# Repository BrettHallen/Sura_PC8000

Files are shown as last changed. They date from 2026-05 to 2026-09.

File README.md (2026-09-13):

# СУРА ПК8000<br>SURA PC8000
Projects for the Soviet "inspired by MSX" computer called the СУРА ПК8000.<br>

Also known as the ВЕСТА (Vesta) and ХОББИ (Hobby).

## YouTube Videos
- [Part 1: First look](https://youtu.be/wWDCWSeaxUg)
- [Part 2: New power supply test](https://youtu.be/me7krCPeANg)

## Useful Links
Mostly in Russian - I use Chrome which has a handy "Translate to English" right-click option.<br>

- [Wikipedia](https://ru.wikipedia.org/wiki/ПК8000)
- [PK8000 site](https://pk8000.narod.ru/)

## [Video Converter](/HDMI_Video_Adaptor_EN)
Work in progress - a video converter designed for Soviet computers.<br>
My only contribution is translating the Python script from Russian to English.<br>

## [PSU Replacement](/Sura_PSU)
Work in progress - my Sura's original 220VAC power supply is very unhappy.  This is my attempt at a simpler, universal (12VDC input) replacement.<br>

I have tested the original Rev. A design ... it works ... but I need to make some tweaks so there will be a Rev. B coming soon.<br>

The original PSU outputs the following via X11 interface:
|X11 port|Voltage|
|---|---|
| X11-5  | +5V |
| X11-6  | +5V |
| X11-8  | -12V  |
| X11-10 | 0V |
| X11-12 | +12V  |
| X11-24 | +12V  |
| X11-25 | +5V |
| X11-26 | +5V |
| X11-27 | 0V |

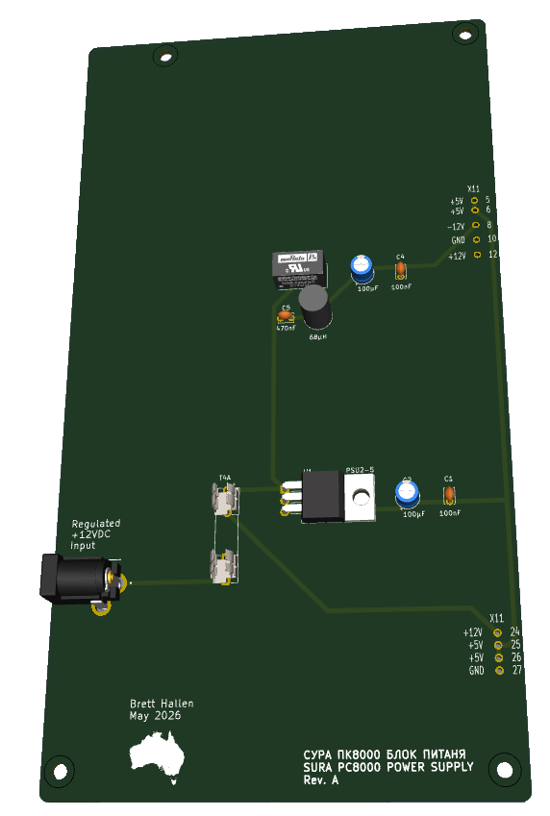
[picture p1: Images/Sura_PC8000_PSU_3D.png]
Replacement PSU 3D


## [Documentation](/Documentation)
Original documentation in Russian, plus any details I've created of my own.<br>
Documentation was sourced from the [PK8000 site](https://pk8000.narod.ru/).

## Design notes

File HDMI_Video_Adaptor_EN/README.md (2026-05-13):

# Video Converter
The hardware design can be found here:<br>
- https://murmulator.ru/rgbtovgahdmi
- https://github.com/AlexEkb4ever/ZX_RGBI2VGA-HDMI

There is a [long discussion thread](https://zx-pk.ru/threads/8375-pk8000-podklyuchaem-k-televizoru(monitoru)/page19.html) about customising, I think, for the PC8000.<br>

That is where I sourced the files here and started the Russian to English translation.<br>

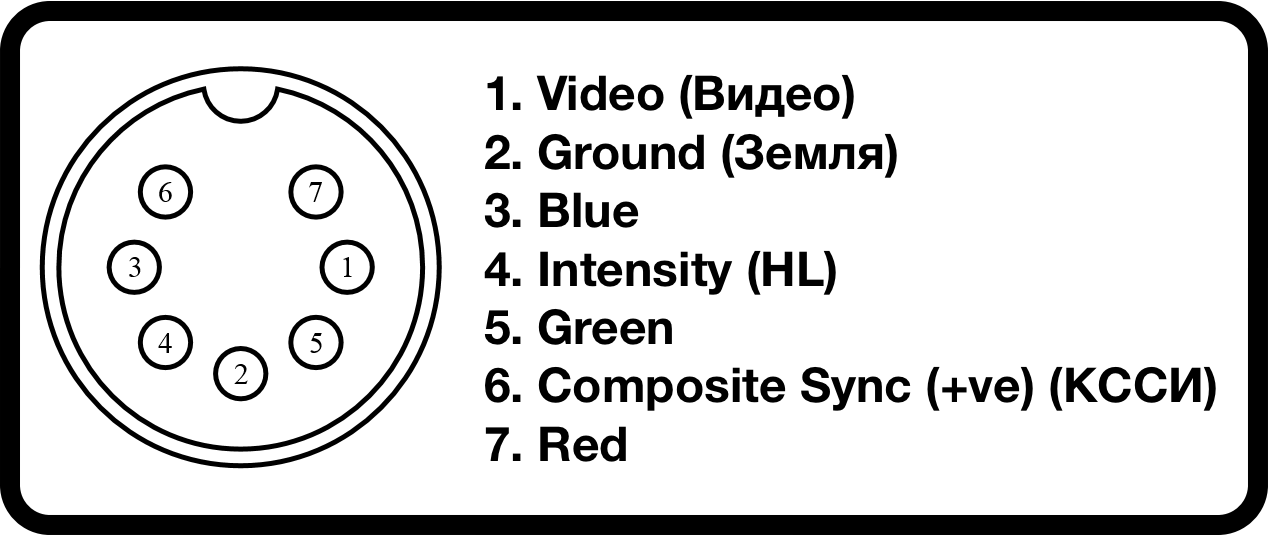
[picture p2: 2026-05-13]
Documentation/Sura_PC8000_Video Pinout.png

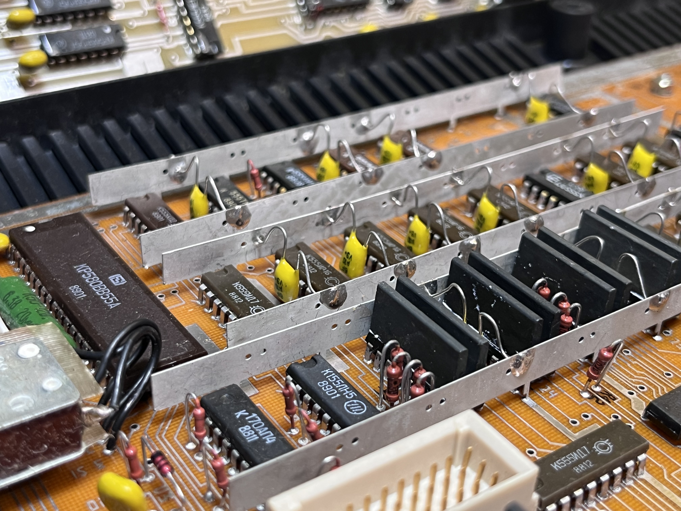
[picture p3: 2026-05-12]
Images/Sura_PC8000_Motherboard1.jpeg

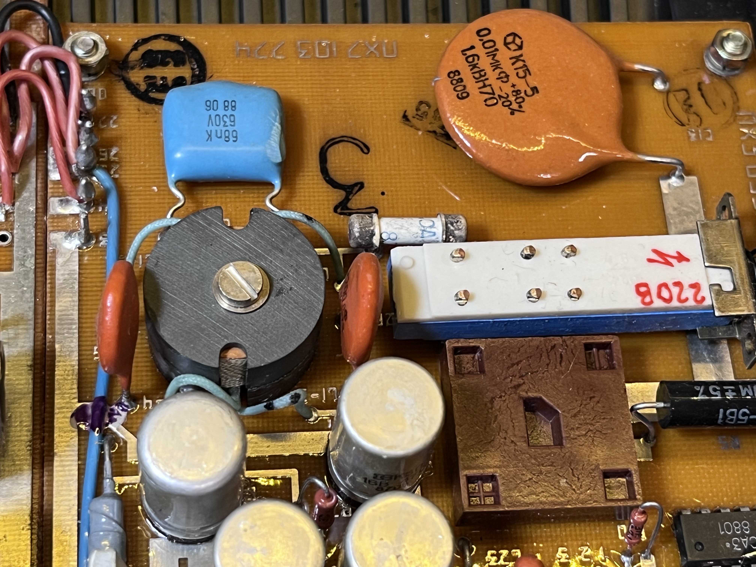
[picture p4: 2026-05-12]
Images/Sura_PC8000_PSU3.jpeg

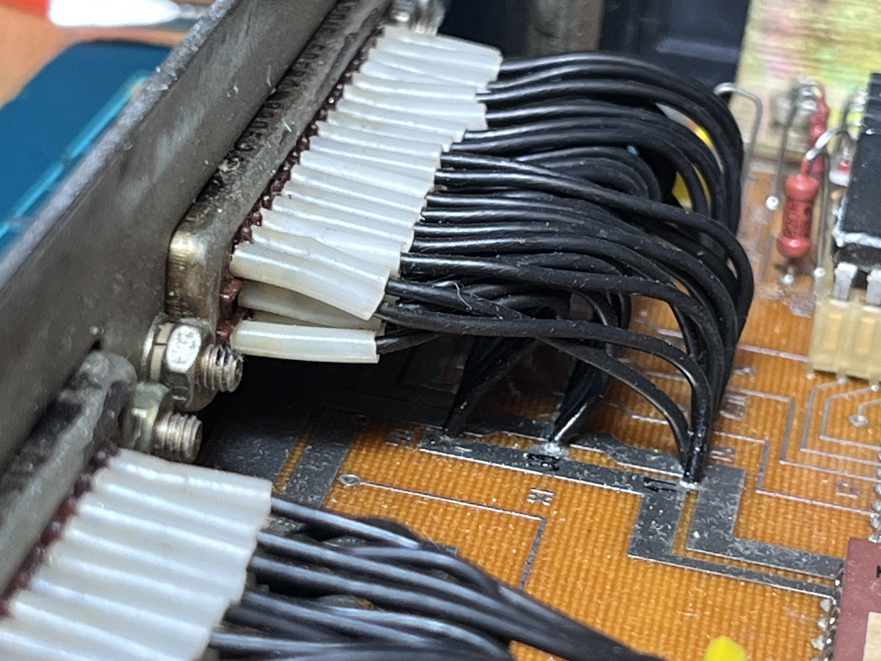
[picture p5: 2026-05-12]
Images/Sura_PC8000_DD50.jpeg

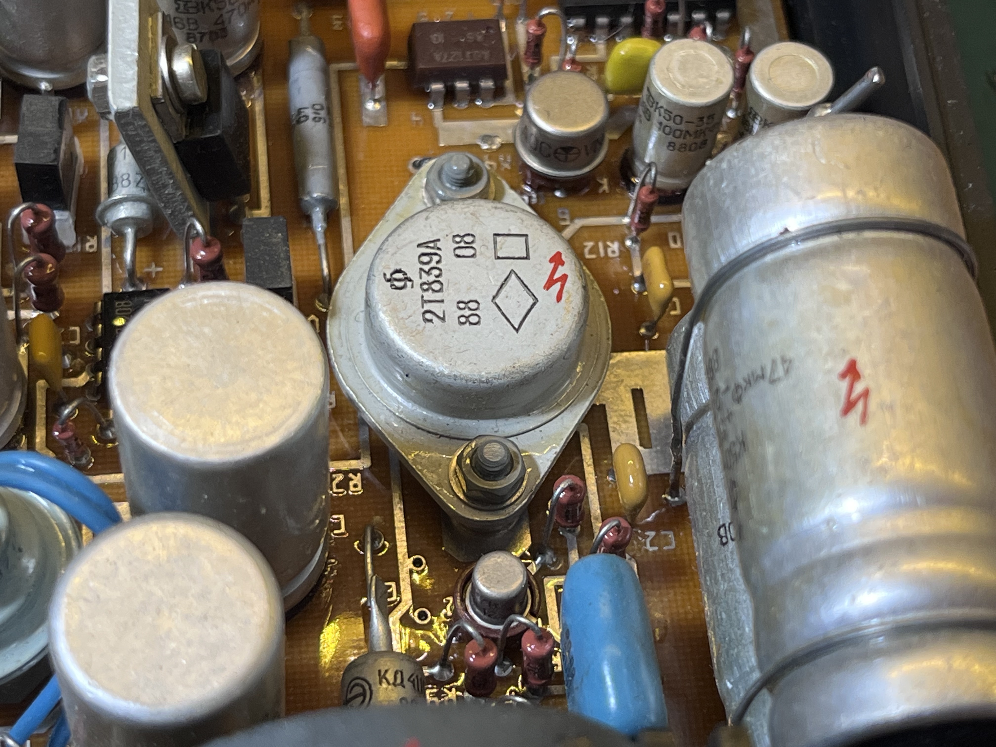
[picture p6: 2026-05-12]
Images/Sura_PC8000_PSU2.jpeg

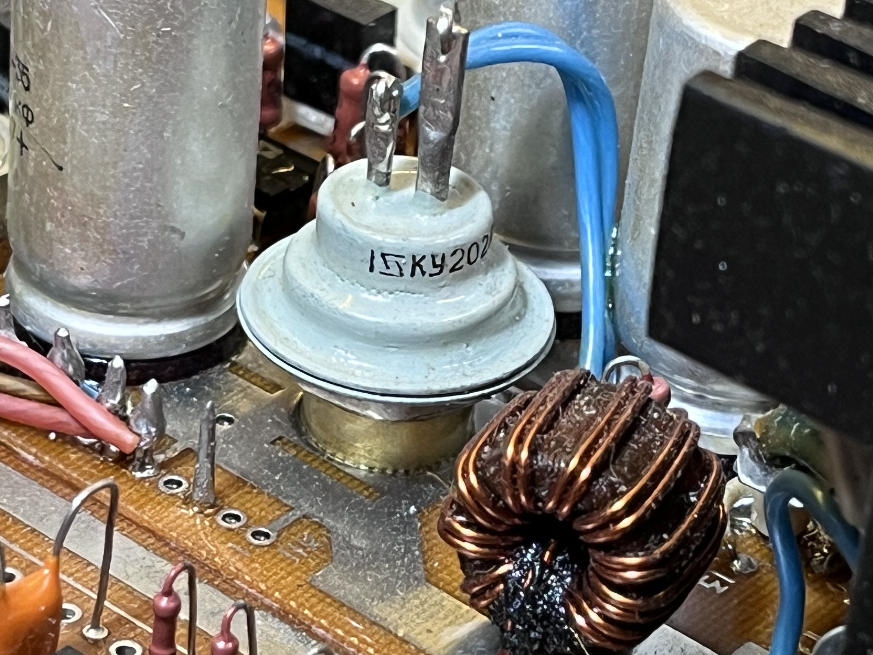
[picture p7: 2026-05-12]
Images/Sura_PC8000_PSU1.jpeg

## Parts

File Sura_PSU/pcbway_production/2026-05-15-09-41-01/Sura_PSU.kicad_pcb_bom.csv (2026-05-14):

Designator | Quantity | Value | Footprint | Package | MPN | DNP | Mount_Type | Description | Manufacturer_Name | Height
C1 | 1 | 22µF 16V | CP_Radial_D5.0mm_P2.50mm |  |  |  | tht | Polarized capacitor
C2 | 1 | 10µF 25V | CP_Radial_D5.0mm_P2.50mm |  |  |  | tht | Polarized capacitor
C3 | 1 | 100µF | CP_Radial_D5.0mm_P2.50mm |  |  |  | tht | Polarized capacitor
C4 | 1 | 100nF | C_Disc_D3.4mm_W2.1mm_P2.50mm |  |  |  | tht | Unpolarized capacitor
C5 | 1 | 470nF | C_Disc_D3.4mm_W2.1mm_P2.50mm |  |  |  | tht | Unpolarized capacitor
F1 | 1 | T4A | Fuseholder_Clip-5x20mm_Littelfuse_111_Inline_P20.00x5.00mm_D1.05mm_Horizontal |  |  |  | tht | Fuse
J1 | 1 | X11 | PinHeader_1x05_P2.54mm_Vertical |  |  |  | tht | Generic connector, single row, 01x05, script generated (kicad-library-utils/schlib/autogen/connector/)
J2 | 1 | 12V In | 694106301002 |  |  |  | tht | DC Barrel Jack with a mounting pin
J3 | 1 | X11 | PinHeader_1x04_P2.54mm_Vertical |  |  |  | tht | Generic connector, single row, 01x04, script generated (kicad-library-utils/schlib/autogen/connector/)
L1 | 1 | 68µH | 22R683C |  |  |  | tht | Inductor
U1 | 1 | DFR0831 | DFR0831 |  |  |  | tht | DC-DC Buck Converter 7-24V to 5V 4A | DFRobot
U2 | 1 | NKE1212SC | NKE1212SC |  | NKE1212SC |  | tht | Murata Power Solutions NKE 1W Isolated DC-DC Converter Through Hole, Voltage in 10.8 13.2 V dc, Voltage out | Murata Electronics | 7.71

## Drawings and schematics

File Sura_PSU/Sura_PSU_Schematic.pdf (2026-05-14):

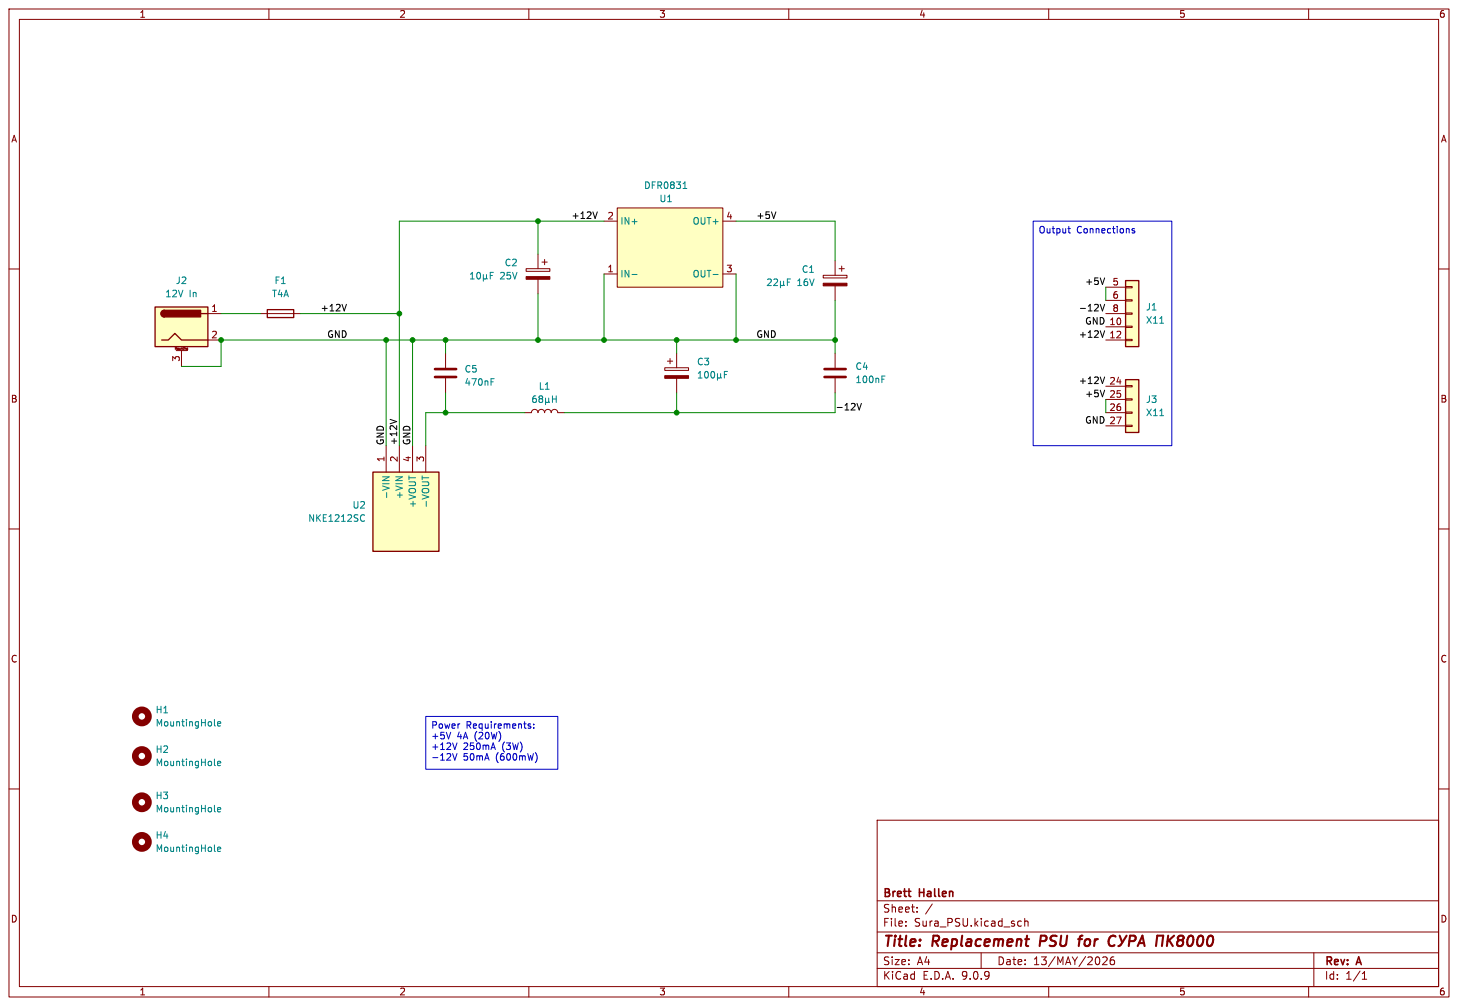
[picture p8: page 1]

12V In H3 MountingHole H4 MountingHole H1 MountingHole H2 MountingHole

Id: 1/1 Title: Replacement PSU for þÿ!# þÿ8000

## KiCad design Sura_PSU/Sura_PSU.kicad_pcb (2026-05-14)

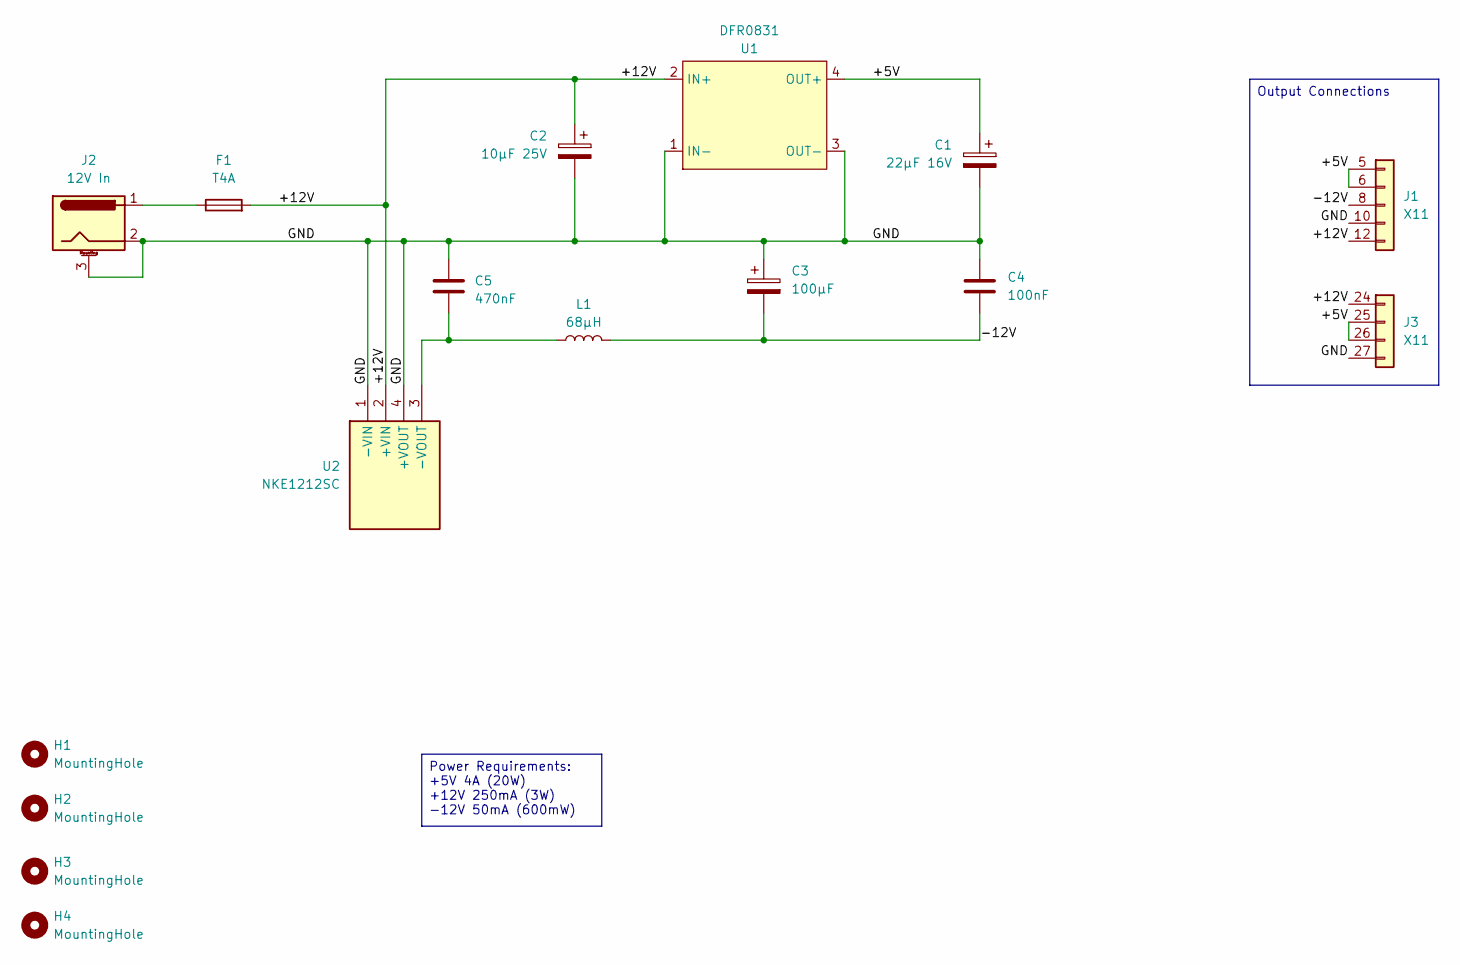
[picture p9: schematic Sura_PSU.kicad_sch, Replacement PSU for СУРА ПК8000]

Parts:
C1: 22µF 16V; CP_Radial_D5.0mm_P2.50mm
C2: 10µF 25V; CP_Radial_D5.0mm_P2.50mm
C3: 100µF; CP_Radial_D5.0mm_P2.50mm
C4: 100nF; C_Disc_D3.4mm_W2.1mm_P2.50mm
C5: 470nF; C_Disc_D3.4mm_W2.1mm_P2.50mm
F1: T4A; Fuseholder_Clip-5x20mm_Littelfuse_111_Inline_P20.00x5.00mm_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
H1, H2, H3, H4: MountingHole; MountingHole_3.2mm_M3
J1: X11; PinHeader_1x05_P2.54mm_Vertical
J2: 12V In; 694106301002
J3: X11; PinHeader_1x04_P2.54mm_Vertical
L1: 68µH; 22R683C
U1: DFR0831
U2: NKE1212SC; Manufacturer_Part_Number NKE1212SC

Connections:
/+5V: C1.1, J1.5 (Pin_1), J1.6 (Pin_2), J3.25 (Pin_2), J3.26 (Pin_3), U1.4 (OUT+)
/+12V: C2.1, F1.2, J1.12 (Pin_5), J3.24 (Pin_1), U1.2 (IN+), U2.2 (+VIN)
/-12V: C3.2, C4.2, J1.8 (Pin_3), L1.2
/GND: C1.2, C2.2, C3.1, C4.1, C5.2, J1.10 (Pin_4), J2.2, J2.3 (MountPin), J3.27 (Pin_4), U1.1 (IN-), U1.3 (OUT-), U2.1 (-VIN), U2.4 (+VOUT)
unnamed: F1.1, J2.1
unnamed: C5.1, L1.1, U2.3 (-VOUT)

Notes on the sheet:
Power Requirements: +5V 4A (20W) +12V 250mA (3W) -12V 50mA (600mW)
Output Connections

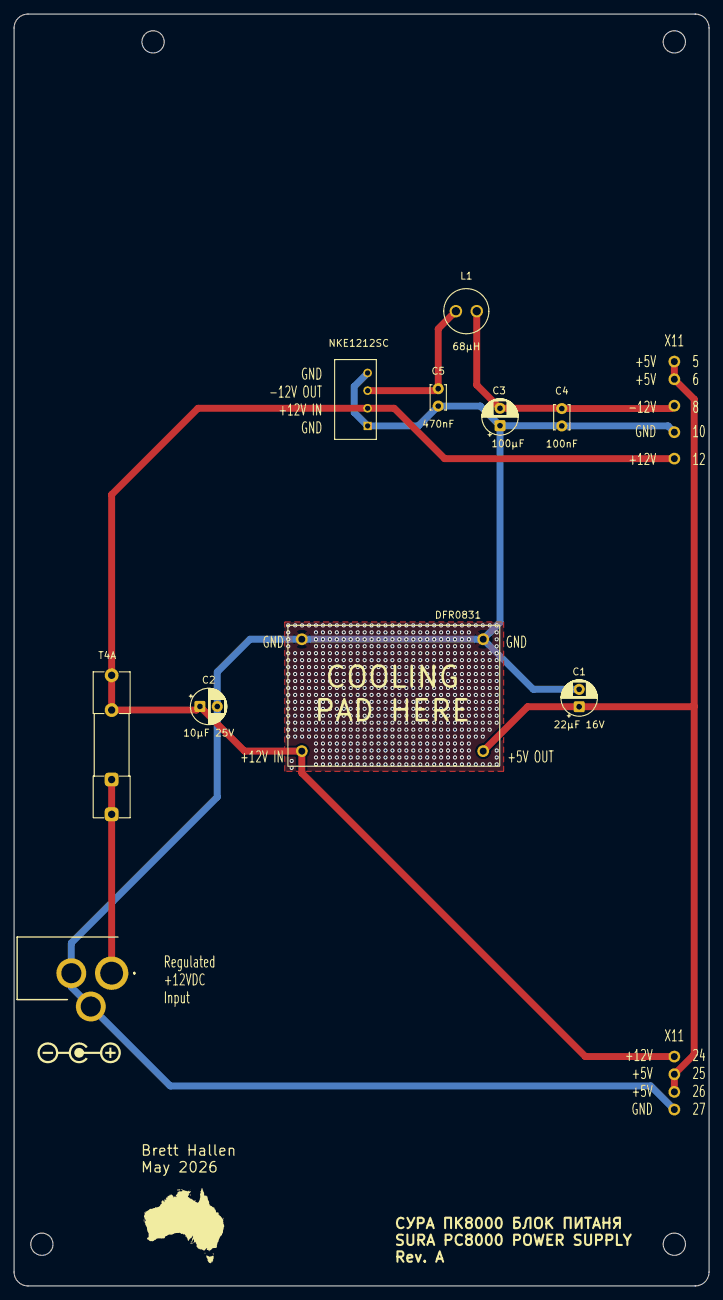
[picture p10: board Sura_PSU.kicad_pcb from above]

Board: 2 copper layers, 100.0 x 183.0 mm, 16 parts (0 on the bottom side), 6 nets.

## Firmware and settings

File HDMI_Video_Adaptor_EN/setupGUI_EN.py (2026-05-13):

# -*- coding: utf-8 -*-

import PySimpleGUI as sg
#import serial.tools.list_ports
import time

import re
import sys
import glob
import serial


def write_ser(ser, key, value):
    return True


def serial_ports():
    """ Lists serial port names

        :raises EnvironmentError:
            On unsupported or unknown platforms
        :returns:
            A list of the serial ports available on the system
    """
    if sys.platform.startswith('win'):
        ports = ['COM%s' % (i + 1) for i in range(256)]
    elif sys.platform.startswith('linux') or sys.platform.startswith('cygwin'):
        # this excludes your current terminal "/dev/tty"
        ports = glob.glob('/dev/tty[A-Za-z]*')
    elif sys.platform.startswith('darwin'):
        ports = glob.glob('/dev/tty.*')
    else:
        raise EnvironmentError('Unsupported platform')

    result = []
    for port in ports:
        try:
            s = serial.Serial(port)
            s.close()
            result.append(port)
        except (OSError, serial.SerialException):
            pass
    return result


# Default theme
sg.change_look_and_feel('SystemDefaultForReal')  # GreenTan

# Get list of serial ports
dev_TTY = serial_ports()  # v2
if len(dev_TTY) == 0:
    dev_TTY = [""]
    sg.PopupNoButtons("No serial ports found", auto_close=True)
    sys.exit()


# Draw the button
namesMode = ('Self-synchronization', 'External frequency', 'From Z80 pin 6')


comboBoxMode = sg.Combo(namesMode, default_value=namesMode[0], size=(20, 1), key='modeName', readonly=True)
comboBoxPorts = sg.InputCombo(dev_TTY, default_value=dev_TTY[0], size=(40, 1), key='portName', readonly=True)

sliderX = sg.Frame(layout=[[
    sg.Slider((200, 0), orientation='h', enable_events=True, key='SLIDERX')
]], title="X Offset", title_location=sg.TITLE_LOCATION_TOP, key='settingsBlock')

sliderY = sg.Frame(layout=[[
    sg.Slider((0, 200), orientation='h', enable_events=True, key='SLIDERY')
]], title="Y Offset", title_location=sg.TITLE_LOCATION_TOP, key='settingsBlock')

sliderF = sg.Frame(layout=[[
    sg.Slider((4000, 11000), orientation='h', enable_events=True, key='-SLIDERF-', size=(250, 20))
]], title="Internal Capture Frequency (kHz)", title_location=sg.TITLE_LOCATION_TOP, key='setting_F_Block')

dividerF = sg.Frame(layout=[[
    sg.Slider((1, 5), orientation='h', enable_events=True, key='-SLIDER_f_div-')
]], title="Divider", title_location=sg.TITLE_LOCATION_TOP, key='dividerFblock')

slider_VS_LEN = sg.Frame(layout=[[
    sg.Slider((50, 500), orientation='h', enable_events=True, key='-SLIDER_VS_LEN-')
]], title="VS Length", title_location=sg.TITLE_LOCATION_TOP, key='settings_VS_LEN_Block')

invBlock = sg.Frame(layout=[[
    sg.CBox('F', size=(3, 1), key='is_inv_F'),
    sg.CBox('KSI', size=(3, 1), key='is_inv_VS'),
    sg.CBox('SSI', size=(3, 1), key='is_inv_HS'),
    sg.CBox('I', size=(3, 1), key='is_inv_I'),
    sg.CBox('R', size=(3, 1), key='is_inv_R'),
    sg.CBox('G', size=(3, 1), key='is_inv_G'),
    sg.CBox('B', size=(3, 1), key='is_inv_B'),
]], title="Invert Input Signals", title_location=sg.TITLE_LOCATION_TOP, key='setting_inv_Block')

sliderDelay0 = sg.Slider((0, 31), orientation='h', enable_events=True, key='-SLIDER_DELAY_0-')

sliderDelay1 = sg.Frame(layout=[[
    sg.Slider((0, 31), orientation='h', enable_events=True, key='-SLIDER_DELAY_1-')
]], title="Rising Edge", title_location=sg.TITLE_LOCATION_TOP, key='-SLIDER_DELAY_BLOCK1-')

sliderDelay2 = sg.Frame(layout=[[
    sg.Slider((0, 31), orientation='h', enable_events=True, key='-SLIDER_DELAY_2-')
]], title="Falling Edge", title_location=sg.TITLE_LOCATION_TOP, key='-SLIDER_DELAY_BLOCK2-')

syncSelect = sg.Frame(layout=[[sg.Radio('Separate', "SYNCMODE", default=True, key="isVS_HS"),
                               sg.Radio('Composite', "SYNCMODE", key="isVHS")],
                              [sg.Push(), slider_VS_LEN, sg.Push()]],
                      title="Synchronization", title_location=sg.TITLE_LOCATION_TOP)

btn1 = sg.Button('Apply', size=(10, 1), key="btn1Click")

block0 = [
    [sg.Frame(layout=[[sg.Radio('VGA', "VIDEOMODE", default=True, size=(5, 1), key="isVGAout", disabled=False),
                       sg.Radio('HDMI', "VIDEOMODE", key="isHDMIout", disabled=False)],
                      [sg.Radio('RGB', "VIDEOMODE", size=(5, 1), key="isRGBout", disabled=True),
                       sg.Radio('COMP', "VIDEOMODE", key="isCOMPout", disabled=True)],
                      [
                          sg.Push(),
                          sg.Frame(layout=[[sg.CBox('Widescreen', key='is_widescreen', disabled=True)]],
                                   title="Aspect Ratio", title_location=sg.TITLE_LOCATION_TOP, key="WIDE_MODE_BLOCK"),
                          sg.Push()
                      ],
                      [
                          sg.Frame(layout=[[sg.Radio('PAL (50Hz)', "SYS_COLOR_MODE", default=True, key="isPAL", disabled=False),
                                            sg.Radio('NTSC (60Hz)', "SYS_COLOR_MODE", key="isNTSC", disabled=False)]],
                                   title="Standard", title_location=sg.TITLE_LOCATION_TOP, key="C_MODE_BLOCK")
                      ]],
               title="Video Output", title_location=sg.TITLE_LOCATION_TOP),

     sg.Frame(layout=[[sg.Radio('1X', "BUFMODE", default=True, size=(5, 1), key="is1X_BUFMODE", disabled=False),
                       sg.Radio('3X', "BUFMODE", key="is3X_BUFMODE", disabled=False)]],
              title="Buffering", title_location=sg.TITLE_LOCATION_TOP)
    ],

    [sg.Frame(layout=[[comboBoxPorts]], title="Port Selection",
              title_location=sg.TITLE_LOCATION_TOP, key='portNameBlock')]
]

block1 = [[
    syncSelect,
    sg.Frame(layout=[[comboBoxMode], [dividerF]],
             title="Pixel Clock Source", title_location=sg.TITLE_LOCATION_TOP)
],

    [sliderF]
]

block2 = [[sg.Frame(layout=[

    [sg.Push(), sliderX, sliderY, sg.Push()],

    [sg.Push(), sg.Frame(layout=[[sliderDelay1, sliderDelay2],
                                 [sg.Push(), sliderDelay0, sg.Push()]],
                        title="Capture Delay", title_location=sg.TITLE_LOCATION_TOP, key='delay_cap_block'), sg.Push()],

    [sg.Push(), invBlock, sg.Push()],

], title="", title_location=sg.TITLE_LOCATION_TOP, key='settingsBlock')]]

blockBTN = [[btn1]]

layout = [
    [sg.Push(), sg.Column(layout=block0, element_justification='c'), sg.Push()],

    [sg.Push(), sg.Column(layout=block1, element_justification='c'), sg.Push()],

    [sg.Push(), sg.Column(layout=block2, element_justification='c'), sg.Push()],

    [sg.Push(), sg.Column(layout=blockBTN, element_justification='c'), sg.Push()],
]

# Draw the window
window = sg.Window('RGB to VGA & HDMI Settings', layout, font=('', 12), margins=(10, 0),
                   size=(600, 650), default_element_size=(40, 1), scaling=True, grab_anywhere=False)

ser = None
oldSerName = None
itst = 0
x_sh = '0'
y_sh = '0'
l_mode = 'read'

while True:
    event, values = window.read(timeout=100)
    if event is None:
        break

    # Check serial port connection
    xnew = int(values['SLIDERX'])
    ynew = int(values['SLIDERY'])

    if event == '__TIMEOUT__':
        # Change of serial port
        if comboBoxPorts.get() != oldSerName:
            if l_mode != 'write':
                l_mode = 'read'
            ser_name = comboBoxPorts.get()
            if ser is None:
                while ser is None:
                    try:
                        ser = serial.Serial(ser_name, 115200, timeout=0.001)
                        oldSerName = ser_name
                    except:
                        ser = None
                        print("create serial " + ser_name + " error")
                        time.sleep(1)
            else:
                ser.close()
                ser = serial.Serial(ser_name, 115200, timeout=0.001)
                oldSerName = ser_name

    # Saving all settings
    if event == 'btn1Click':
        sg.PopupNoButtons("Rebooting board, please wait...", auto_close=True)
        l_mode = 'write'

    # Mode selection
    modeName = window['modeName'].get()

    if modeName == namesMode[0]:  # Self-synchronization
        window['dividerFblock'].hide_row()
        window['setting_F_Block'].unhide_row()
        window['-SLIDER_DELAY_0-'].unhide_row()
        window['-SLIDER_DELAY_BLOCK1-'].hide_row()
        window['-SLIDER_DELAY_BLOCK2-'].hide_row()

    if modeName == namesMode[1]:  # External frequency
        window['dividerFblock'].unhide_row()
        window['setting_F_Block'].hide_row()
        window['-SLIDER_DELAY_0-'].unhide_row()
        window['-SLIDER_DELAY_BLOCK1-'].hide_row()
        window['-SLIDER_DELAY_BLOCK2-'].hide_row()

    if modeName == namesMode[2]:  # From Z80 pin 6
        window['dividerFblock'].hide_row()
        window['setting_F_Block'].hide_row()
        window['-SLIDER_DELAY_0-'].hide_row()
        window['-SLIDER_DELAY_BLOCK1-'].unhide_row()
        window['-SLIDER_DELAY_BLOCK2-'].unhide_row()

    if window['isHDMIout'].get():
        window['C_MODE_BLOCK'].hide_row()
        window['WIDE_MODE_BLOCK'].unhide_row()

    if window['isVGAout'].get():
        window['C_MODE_BLOCK'].hide_row()
        window['WIDE_MODE_BLOCK'].unhide_row()

    if window['isRGBout'].get():
        window['C_MODE_BLOCK'].unhide_row()
        window['WIDE_MODE_BLOCK'].hide_row()

    if window['isCOMPout'].get():
        window['C_MODE_BLOCK'].unhide_row()
        window['WIDE_MODE_BLOCK'].hide_row()

    if window['isVHS'].get():
        window['settings_VS_LEN_Block'].unhide_row()
    if window['isVS_HS'].get():
        window['settings_VS_LEN_Block'].hide_row()

    # Serial port communication
    if event == '__TIMEOUT__':
        if ser is not None:
            try:
                # Check hardware mode
                ser.write("mode\n".encode())
                time.sleep(0.1)
                hw_mode = str(ser.readall())

                # mode 0 - read/write parameters
                if hw_mode.find("mode 0") > 0:
                    print("hw mode 0")

                    # Save to chip
                    if l_mode == 'write':
                        sg.PopupNoButtons("Saving parameters...", auto_close=True)

                        ser.write(("wcap_sh_x " + str(int(values['SLIDERX'])) + "\n").encode())
                        time.sleep(0.01)
                        ser.readall()

                        ser.write(("wcap_sh_y " + str(int(values['SLIDERY'])) + "\n").encode())
                        time.sleep(0.01)
                        ser.readall()

                        ser.write(("wcap_ext_f_div " + str(int(values['-SLIDER_f_div-'])) + "\n").encode())
                        time.sleep(0.01)
                        ser.readall()

                        ser.write(("wcap_int_f " + str(int(values['-SLIDERF-'])) + "000\n").encode())
                        time.sleep(0.01)
                        ser.readall()

                        ser.write(("wcap_delay " + str(int(values['-SLIDER_DELAY_0-'])) + "\n").encode())
                        time.sleep(0.01)
                        ser.readall()

                        ser.write(("wcap_delay_rise " + str(int(values['-SLIDER_DELAY_1-'])) + "\n").encode())
                        time.sleep(0.01)
                        ser.readall()

                        ser.write(("wcap_delay_fall " + str(int(values['-SLIDER_DELAY_2-'])) + "\n").encode())
                        time.sleep(0.01)
                        ser.readall()

                        ser.write(("wcap_len_VS " + str(int(values['-SLIDER_VS_LEN-'])) + "\n").encode())
                        time.sleep(0.01)
                        ser.readall()

                        iD = 0
                        if values['isHDMIout']:
                            iD = 1
                        if values['isRGBout']:
                            iD = 2
                        if values['isCOMPout']:
                            iD = 3
                        ser.write(("wvideo_out " + str(int(iD)) + "\n").encode())
                        time.sleep(0.01)
                        ser.readall()

                        iD = 0
                        if values['isNTSC']:
                            iD = 1
                        ser.write(("wc_mode " + str(int(iD)) + "\n").encode())
                        time.sleep(0.01)
                        ser.readall()

                        iD = 0
                        if values['is3X_BUFMODE']:
                            iD = 1
                        ser.write(("wis_3X_bufmode " + str(int(iD)) + "\n").encode())
                        time.sleep(0.01)
                        ser.readall()

                        iD = 0
                        if values['isVHS']:
                            iD = 1
                        ser.write(("wcap_sync_mode " + str(int(iD)) + "\n").encode())
                        time.sleep(0.01)
                        ser.readall()

                        iD = 0
                        if values['is_widescreen']:
                            iD = 1
                        ser.write(("wwide_mode " + str(int(iD)) + "\n").encode())
                        time.sleep(0.01)
                        ser.readall()

                        iD = 0
                        if values['modeName'] == namesMode[1]:
                            iD = 1
                        if values['modeName'] == namesMode[2]:
                            iD = 2
                        ser.write(("wcap_p_clk_mode " + str(int(iD)) + "\n").encode())
                        time.sleep(0.01)
                        ser.readall()

                        iD = 0
                        if values['is_inv_F']:
                            iD |= 1
                        iD <<= 1
                        if values['is_inv_VS']:
                            iD |= 1
                        iD <<= 1
                        if values['is_inv_HS']:
                            iD |= 1
                        iD <<= 1
                        if values['is_inv_I']:
                            iD |= 1
                        iD <<= 1
                        if values['is_inv_R']:
                            iD |= 1
                        iD <<= 1
                        if values['is_inv_G']:
                            iD |= 1
                        iD <<= 1
                        if values['is_inv_B']:
                            iD |= 1
                        ser.write(("wcap_in_inv_mask " + str(int(iD)) + "\n").encode())
                        time.sleep(0.01)
                        ser.readall()

                        print("saving data")
                        l_mode = 'user_mode'
                        ser.write("save\n".encode())
                        continue

                    # Read from chip
                    if l_mode == 'read':
                        sg.PopupNoButtons("Loading parameters...", auto_close=True)

                        ser.write("rcap_sh_x\n".encode())
                        time.sleep(0.01)
                        s1 = str(ser.readall())
                        i_data = int(''.join(x for x in s1 if x.isdigit()))
                        window['SLIDERX'].update(value=i_data)

                        ser.write("rcap_sh_y\n".encode())
                        time.sleep(0.01)
                        s1 = str(ser.readall())
                        i_data = int(''.join(x for x in s1 if x.isdigit()))
                        window['SLIDERY'].update(value=i_data)

                        ser.write("rcap_ext_f_div\n".encode())
                        time.sleep(0.01)
                        s1 = str(ser.readall())
                        i_data = int(''.join(x for x in s1 if x.isdigit()))
                        window['-SLIDER_f_div-'].update(value=i_data)

                        ser.write("rcap_int_f\n".encode())
                        time.sleep(0.01)
                        s1 = str(ser.readall())
                        i_data = int(''.join(x for x in s1 if x.isdigit()))
                        window['-SLIDERF-'].update(value=i_data / 1000)

                        ser.write("rcap_delay\n".encode())
                        time.sleep(0.01)
                        s1 = str(ser.readall())
                        i_data = int(''.join(x for x in s1 if x.isdigit()))
                        window['-SLIDER_DELAY_0-'].update(value=i_data)

                        ser.write("rcap_delay_rise\n".encode())
                        time.sleep(0.01)
                        s1 = str(ser.readall())
                        i_data = int(''.join(x for x in s1 if x.isdigit()))
                        window['-SLIDER_DELAY_1-'].update(value=i_data)

                        ser.write("rcap_delay_fall\n".encode())
                        time.sleep(0.01)
                        s1 = str(ser.readall())
                        i_data = int(''.join(x for x in s1 if x.isdigit()))
                        window['-SLIDER_DELAY_2-'].update(value=i_data)

                        ser.write("rcap_len_VS\n".encode())
                        time.sleep(0.01)
                        s1 = str(ser.readall())
                        i_data = int(''.join(x for x in s1 if x.isdigit()))
                        window['-SLIDER_VS_LEN-'].update(value=i_data)

                        ser.write("rwide_mode\n".encode())
                        time.sleep(0.01)
                        s1 = str(ser.readall())
                        i_data = int(''.join(x for x in s1 if x.isdigit()))
                        window['is_widescreen'].update(i_data == 1)

                        ser.write("rvideo_out\n".encode())
                        time.sleep(0.01)
                        s1 = str(ser.readall())
                        i_data = int(''.join(x for x in s1 if x.isdigit()))
                        if i_data == 0:
                            window['isVGAout'].update(True)
                        if i_data == 1:
                            window['isHDMIout'].update(True)
                        if i_data == 2:
                            window['isRGBout'].update(True)
                        if i_data == 3:
                            window['isCOMPout'].update(True)

                        ser.write("rc_mode\n".encode())
                        time.sleep(0.01)
                        s1 = str(ser.readall())
                        i_data = int(''.join(x for x in s1 if x.isdigit()))
                        if i_data == 0:
                            window['isPAL'].update(True)
                        if i_data == 1:
                            window['isNTSC'].update(True)

                        ser.write("ris_3X_bufmode\n".encode())
                        time.sleep(0.01)
                        s1 = str(ser.readall())
                        i_data = int(''.join(x for x in s1 if x.isdigit()))
                        if i_data == 30:
                            window['is1X_BUFMODE'].update(True)
                        if i_data == 31:
                            window['is3X_BUFMODE'].update(True)

                        ser.write("rcap_sync_mode\n".encode())
                        time.sleep(0.01)
                        s1 = str(ser.readall())
                        i_data = int(''.join(x for x in s1 if x.isdigit()))
                        if i_data == 0:
                            window['isVS_HS'].update(True)
                        if i_data == 1:
                            window['isVHS'].update(True)

                        ser.write("rcap_p_clk_mode\n".encode())
                        time.sleep(0.01)
                        s1 = str(ser.readall())
                        i_data = int(''.join(x for x in s1 if x.isdigit()))
                        window['modeName'].update(namesMode[i_data])

                        ser.write("rcap_in_inv_mask\n".encode())
                        time.sleep(0.01)
                        s1 = str(ser.readall())
                        i_data = int(''.join(x for x in s1 if x.isdigit()))
                        window['is_inv_B'].update(i_data & 1)
                        i_data >>= 1
                        window['is_inv_G'].update(i_data & 1)
                        i_data >>= 1
                        window['is_inv_R'].update(i_data & 1)
                        i_data >>= 1
                        window['is_inv_I'].update(i_data & 1)
                        i_data >>= 1
                        window['is_inv_HS'].update(i_data & 1)
                        i_data >>= 1
                        window['is_inv_VS'].update(i_data & 1)
                        i_data >>= 1
                        window['is_inv_F'].update(i_data & 1)

                        l_mode = 'user_mode'
                        ser.write("exit\n".encode())
                        continue

                # mode 1 - offset adjustment only
                if hw_mode.find("mode 1") > 0:
                    print("hw mode 1")

                    if l_mode != 'user_mode':
                        print("restart hw")
                        ser.write("reset\n".encode())
                        time.sleep(0.1)
                        continue

                    if x_sh != xnew:
                        st1 = "wcap_sh_x " + str(xnew)
                        ser.write(st1.encode())
                        x_sh = xnew
                        time.sleep(0.1)
                        print(str(ser.readall()))

                    if y_sh != ynew:
                        st1 = "wcap_sh_y " + str(ynew)
                        ser.write(st1.encode())
                        y_sh = ynew
                        time.sleep(0.1)
                        print(str(ser.readall()))

            except:
                print("error serial")
                ser.close()
                time.sleep(0.1)
                ser = None
                oldSerName = None

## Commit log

2026-05-13 "бидео" to "видео" (doh)
2026-05-13 Initial design started
    [Sura_PSU.kicad_pcb, Sura_PSU.kicad_sch]
2026-05-14 Initial commit (to be tested)
    [Sura_PSU.kicad_pcb, Sura_PSU.kicad_pcb_bom.csv, Sura_PSU.kicad_pcb_positions.csv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]
2026-05-14 Updated design (swapped 5V regulator)
    [Sura_PSU.kicad_pcb, Sura_PSU.kicad_pcb_bom.csv, Sura_PSU.kicad_pcb_positions.csv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]
